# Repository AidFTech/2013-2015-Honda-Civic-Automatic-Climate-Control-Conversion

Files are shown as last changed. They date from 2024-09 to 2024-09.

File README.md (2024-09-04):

# 2013-2015 Honda Civic Automatic Climate Control Conversion

This device allows for a plug-and-play conversion of the manual climate control provided in the 2013-2015 Civic LX, GX, HF, and Si (US) to the automatic climate control provided in the EX and EX-L trims.

All files required to build and program the device are included in this repository.

Refer to [this](https://youtu.be/0c5TGwSvMb4) YouTube video for instructions if you have never built a black box before.

Questions? Comments? Concerns? Email me at [aidancivicminded@gmail.com](aidancivicminded@gmail.com).

## PCB Fabrication

The Gerber files required for PCB fabrication can be downloaded from Hardware/PCB. This folder also contains the EasyEDA PCB and schematic files in JSON form. These can be loaded into the EasyEDA online editor for part number references as shown in the instruction video. The parts lists can be found under ./Bill of Materials. To place an order from DigiKey, use the file "BOM_9th gen Civic Automatic Climate Control Conversion_BulkOrder.csv"

## Enclosure Fabrication

The enclosure model files are included in Hardware/Enclosure.

## Programming

This device uses an AVR Atmega328P microcontroller with Arduino bootloader. The Arduino software is free to download from [this page](https://www.arduino.cc/en/software), and the Arduino Uno can be ordered from the same website. All code for this device can be found under Software/Auto_Climate_CAN_Filter.

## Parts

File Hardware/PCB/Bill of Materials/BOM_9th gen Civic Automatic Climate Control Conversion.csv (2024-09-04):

ID | Name | Designator | Footprint | Quantity | Manufacturer Part | Manufacturer | Supplier | Supplier Part
1 | 100u | C1 | CAP-D8.0-F3.5 | 1 | 50ZLH100MEFC8X11.5 | Rubycon | Digi-Key | 1189-2327-ND
2 | 0.1uF | C2,C4,C7,C9,C10,C13,C16,C20 | C0603 | 8 | 0603B104K101CT | Walsin Technology Corporation | Digi-Key | 1292-1392-1-ND
3 | 470uF | C3 | CAP-D8.0-F3.5 | 1 | 860020474014 | Würth Elektronik | Digi-Key | 732-8831-1-ND
4 | 22pF | C5,C6,C8,C14,C15,C17 | C0603 | 6 | 0603N220F500CT | Walsin Technology Corporation | Digi-Key | 1292-1500-1-ND
5 | 560pF | C11,C12,C18,C19 | C0603 | 4 | 06031C561KAT2A | AVX Corporation | Digi-Key | 478-5002-1-ND
6 | PESD1CAN | D1,D2 | SOT-23_L2.9-W1.3-P1.90-LS2.4-BR | 2 | PESD1CAN-UX | Nexperia USA Inc. | Digi-Key | 1727-1306-1-ND
7 | MX34032UF2 | J1 | MX34032UF2 | 1 | MX34032UF2 | JAE Electronics | Digi-Key | 670-2910-ND
8 | 53254-0270 | J2 | MOLEX_53254-0270 | 1 | 532540270 | Molex | Digi-Key | WM18999-ND
9 | B04B-PASK | J3,J4 | CONN-TH_B04B-PASK-LF-SN | 2 | B04B-PASK(LF)(SN) | JST Sales America Inc. | Digi-Key | 455-1819-ND
10 | 5018763240 | J5 | CONN-TH_32P-P2.00-S2.00_L9.1-W34.0 | 1 | 5018763240 | Molex | Digi-Key | WM12318-ND
11 | S2B-XH-A-BK(LF)(SN) | J6 | CONN-TH_S2B-XH-A-LF-SN | 1 | S2B-XH-A-BK(LF)(SN) | JST | Digi-Key | 455-S2B-XH-A-ND
12 | HDR-M-2.54_1x4 | J7 | HDR-M-2.54_1X4 | 1 | 61300411121 | Würth Elektronik | Digi-Key | 732-5317-ND
13 | SI2347DS-T1-GE3 | Q1 | SOT-23-3_L2.9-W1.3-P1.83-LS2.4-BR-1 | 1 | SI2347DS-T1-GE3 | Vishay Siliconix | Digi-Key | SI2347DS-T1-GE3CT-ND
14 | DMN67D8LW-13 | Q2,Q3 | SOT-323-3_L2.2-W1.3-P1.30-LS2.1-BR | 2 | DMN67D8LW-13 | Diodes Incorporated | Digi-Key | DMN67D8LW-13DICT-ND
15 | 4.7k | R1,R2,R4,R7 | R0603 | 4 | RC0603FR-074K7P | Yageo | Digi-Key | YAG1304CT-ND
16 | 10k | R3 | R0603 | 1 | RNCP0603FTD10K0 | Stackpole Electronics Inc | Digi-Key | RNCP0603FTD10K0CT-ND
17 | 100 | R5,R6,R8,R9,R10 | R0603 | 5 | CRCW0603100RFKEAHP | Vishay Dale | Digi-Key | 541-100SCT-ND
18 | 7805 | U1 | SOT-223-4_L6.5-W3.5-P2.30-LS7.0-BR | 1 | LM7805MP/NOPB | Texas Instruments | Digi-Key | 296-44517-1-ND
19 | ATMEGA328P-PU | U2 | DIP-28_L34.6-W7.3-P2.54-LS10.2-BL | 1 | ATMEGA328P-PU | Microchip Technology | Digi-Key | ATMEGA328P-PU-ND
20 | MCP4921T-E/MS | U3 | 8-SOIC-3.9MM | 1 | MCP4921-E/SN | Microchip Technology | Digi-Key | MCP4921-E/SN-ND
21 | MCP2515T-I/SO | U4,U7 | SOIC-18_L11.6-W7.5-P1.27-LS10.3-BL | 2 | MCP2515T-I/SO | Microchip Technology | Digi-Key | MCP2515T-I/SOCT-ND
22 | MCP2551T-I/SN | U5,U6 | SOIC-8_L4.9-W3.9-P1.27-LS6.0-BL-2 | 2 | MCP2551-I/SN | Microchip Technology | Digi-Key | MCP2551-I/SN-ND
23 | 16MHz | X1,X2,X3 | HC-49US-SMD_L7.0-W4.1 | 3 | ECS-160-20-3X-EN-TR | ECS Inc. | Digi-Key | XC1793CT-ND

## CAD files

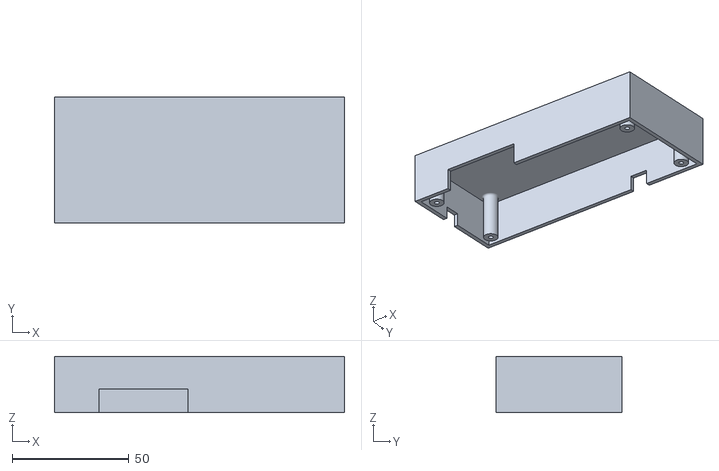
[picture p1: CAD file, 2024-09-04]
Hardware/Enclosure/Enclosure Top.stl
124.0 x 54.0 x 24.0

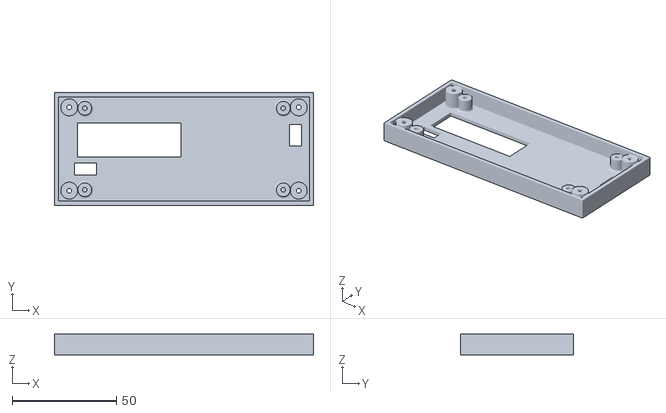
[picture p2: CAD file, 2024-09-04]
Hardware/Enclosure/Enclosure Bottom.stl
124.0 x 54.0 x 10.0

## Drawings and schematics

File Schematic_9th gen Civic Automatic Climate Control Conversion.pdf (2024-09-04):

## JAE MX340032F2

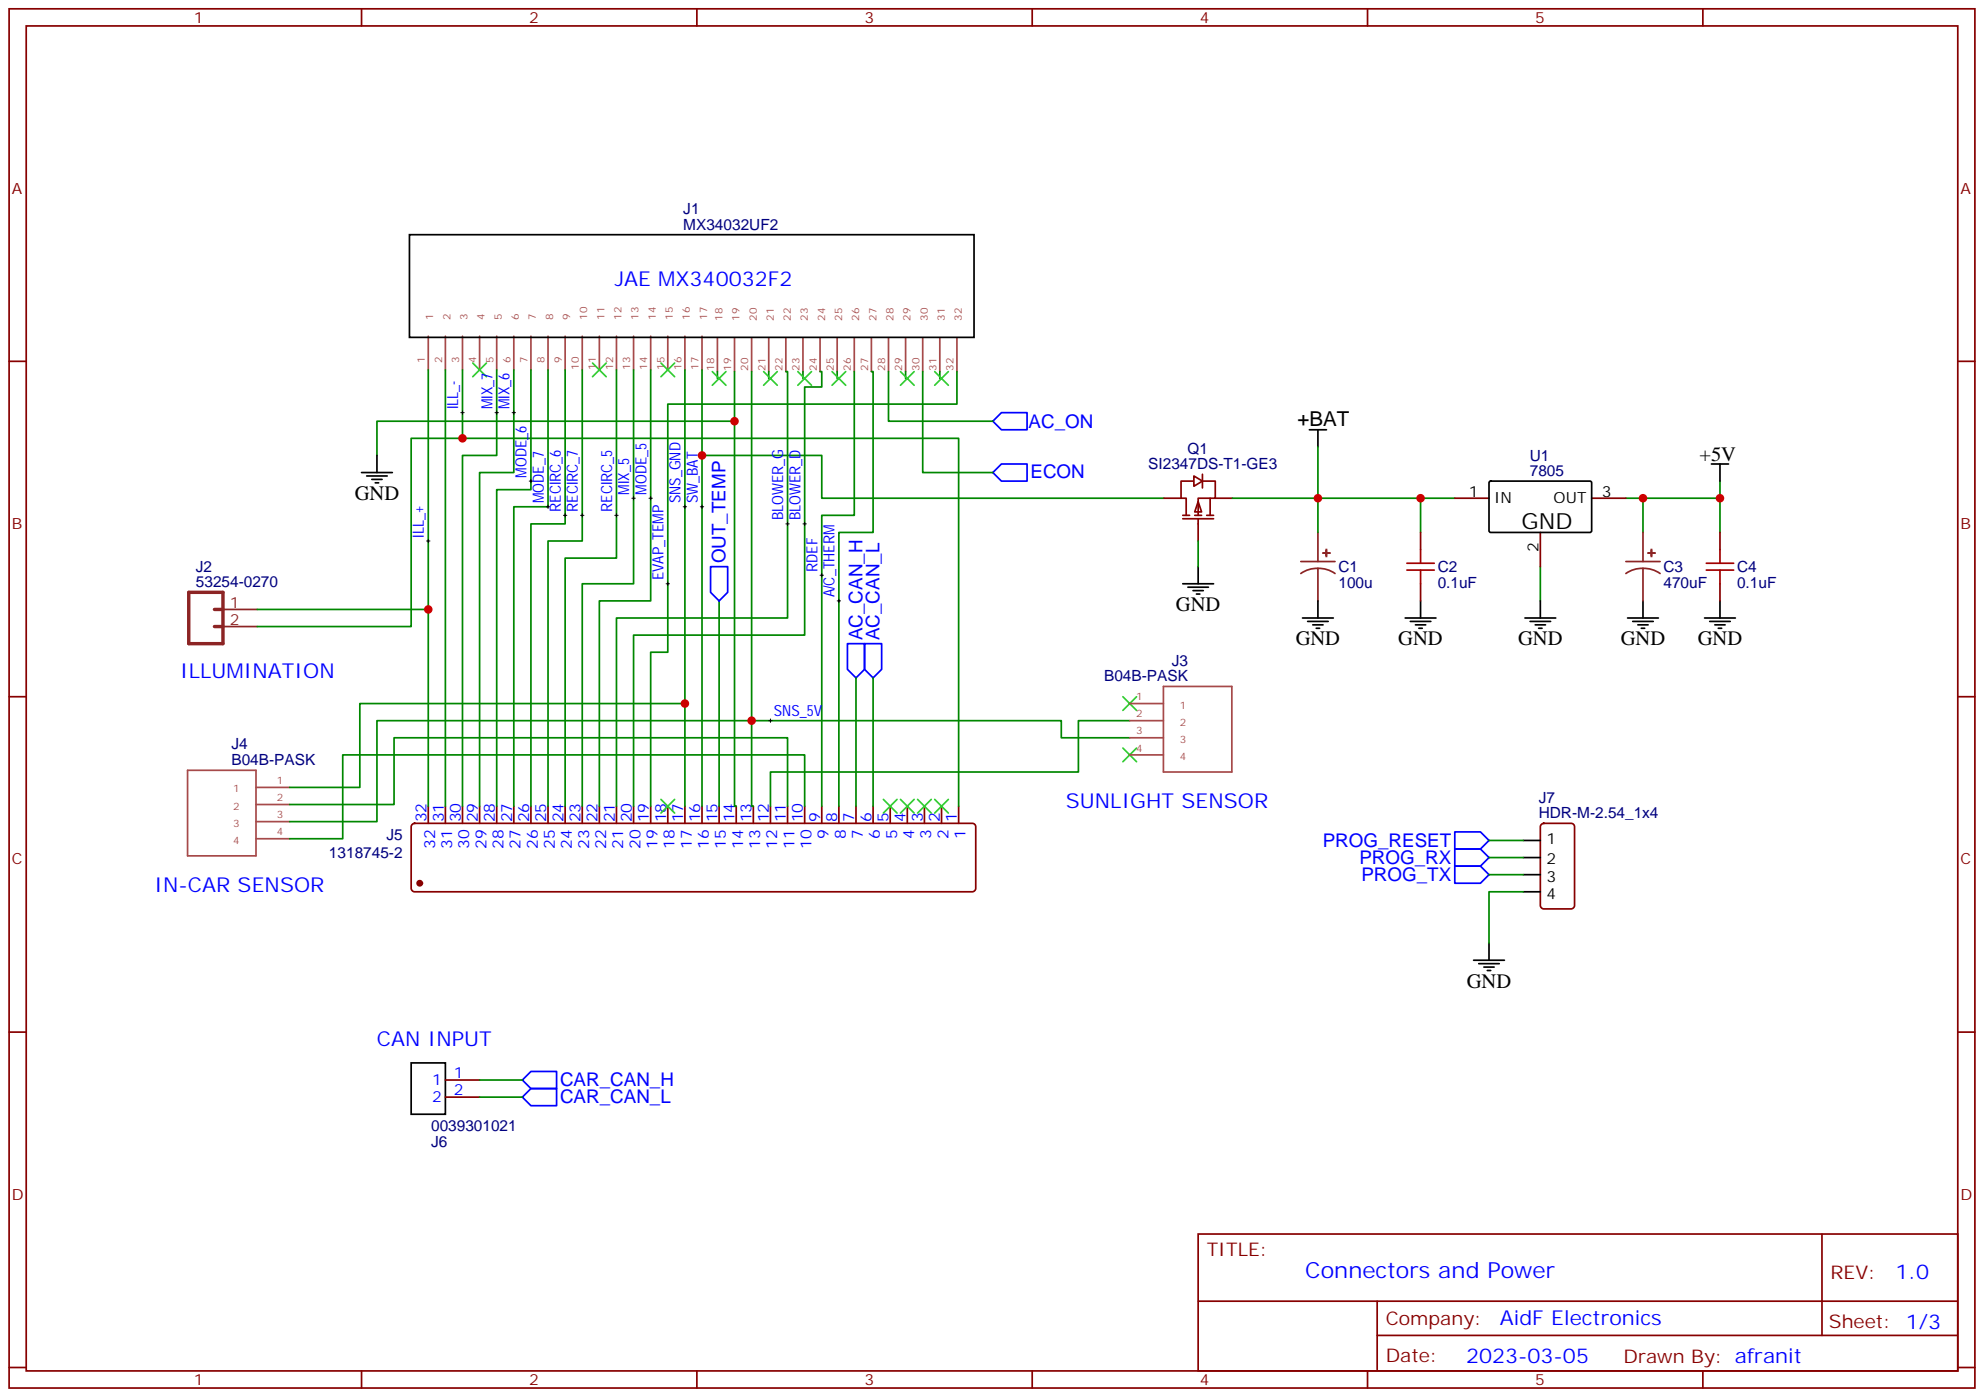
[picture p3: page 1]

# GNDAC_ON

## RESET

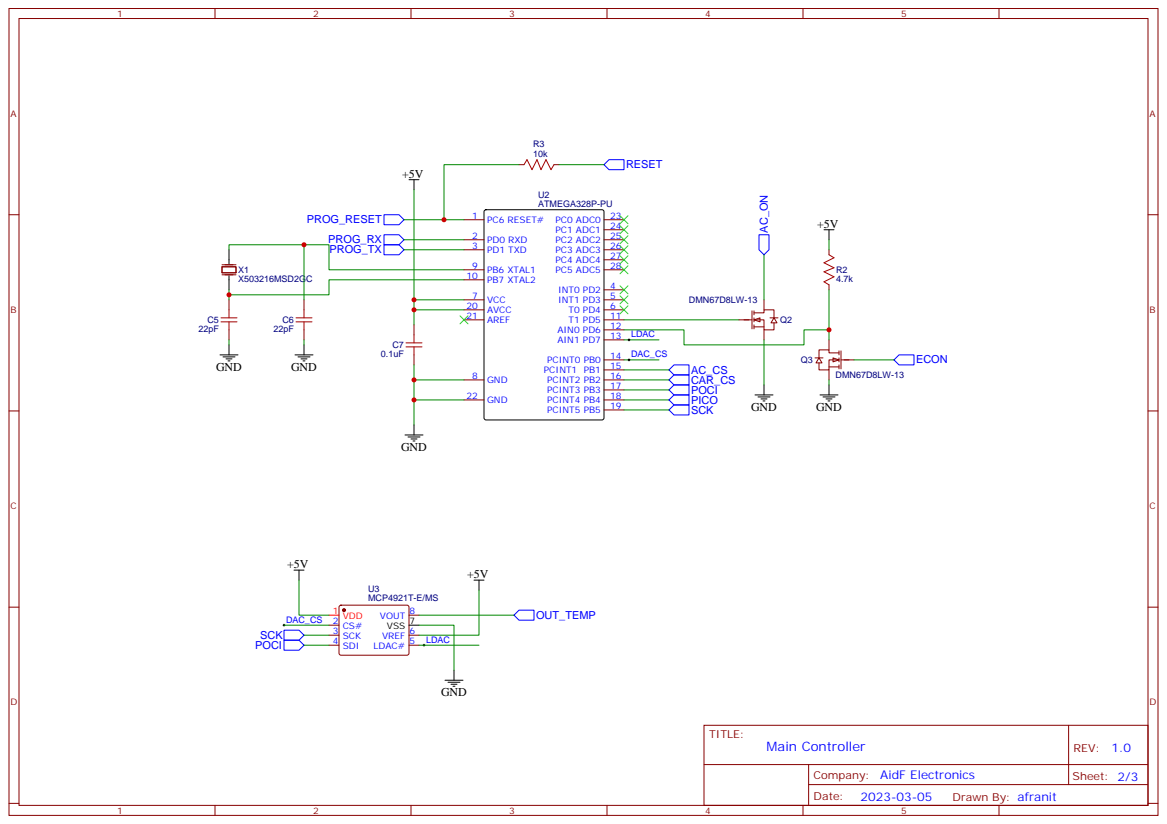
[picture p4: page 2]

## RESET

## POCI

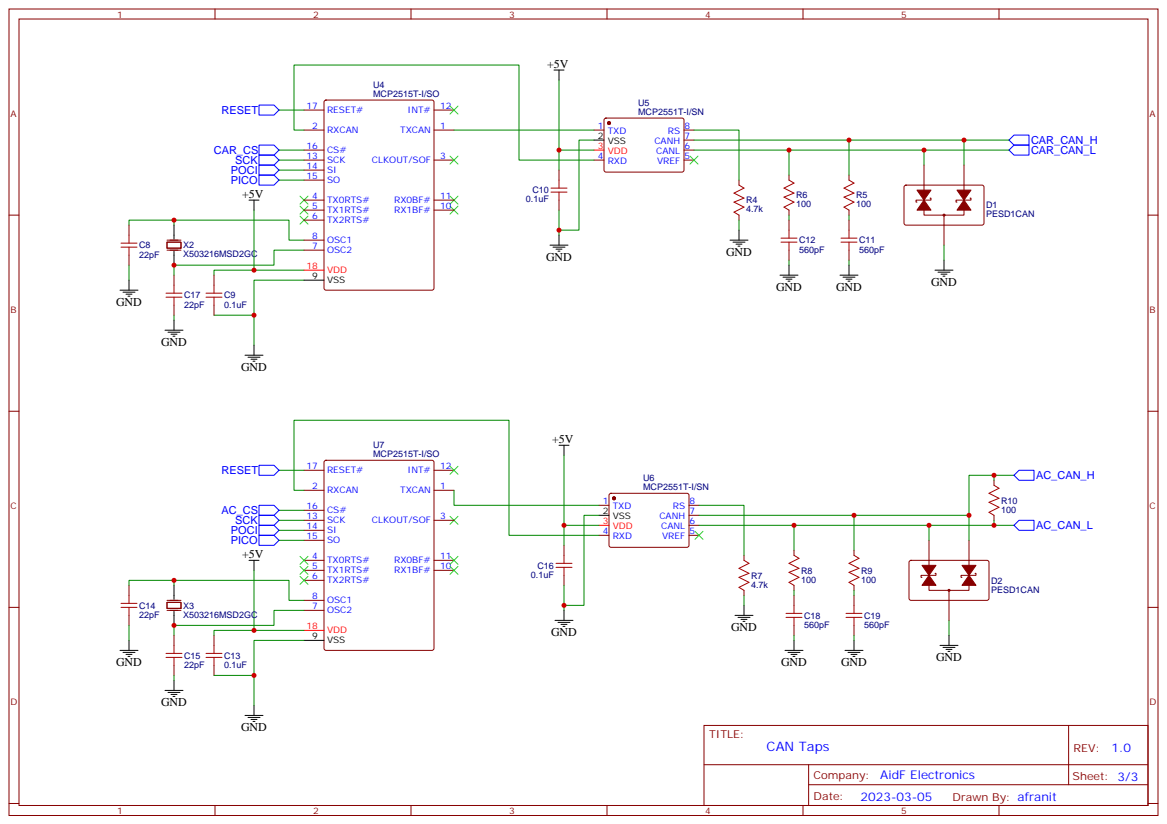
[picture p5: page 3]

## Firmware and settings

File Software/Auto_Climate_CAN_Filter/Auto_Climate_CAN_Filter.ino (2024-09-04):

#include <stdint.h>
#include <mcp2515.h>
#include <SPI.h>

#include "Auto_Climate_Translator.h"

#define AC_PIN 5
#define ECON_PIN 6
#define LDAC 7
#define DAC_CS 8

MCP2515 can_car(10);
MCP2515 can_unit(9);

AutoClimateTranslator auto_translator(&can_car, &can_unit, AC_PIN, ECON_PIN, DAC_CS, LDAC); 

void setup() {
	can_car.reset();
	can_car.setBitrate(CAN_125KBPS);
	can_car.setNormalMode();
	
	can_unit.reset();
	can_unit.setBitrate(CAN_125KBPS);
	can_unit.setNormalMode();
	
	pinMode(LDAC, OUTPUT);
	pinMode(DAC_CS, OUTPUT);
	auto_translator.sendStartDAC();
}

void loop() {
	auto_translator.getCANMessages();
}

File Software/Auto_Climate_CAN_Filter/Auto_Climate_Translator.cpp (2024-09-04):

#include "Auto_Climate_Translator.h"

AutoClimateTranslator::AutoClimateTranslator(MCP2515* car_can, MCP2515* unit_can, uint8_t ac_pin, uint8_t econ_pin, uint8_t dac_cs, uint8_t dac_latch) {
	this->car_can = car_can;
	this->unit_can = unit_can;
	
	this->ac_pin = ac_pin;
	this->econ_pin = econ_pin;
	
	this->dac_cs = dac_cs;
	this->dac_latch = dac_latch;
	
	pinMode(this->ac_pin, OUTPUT);
	digitalWrite(this->ac_pin, LOW);
	
	#ifdef ECONOMY_AVAILABLE
	pinMode(this->econ_pin, INPUT);
	#endif
}

void AutoClimateTranslator::getCANMessages() {
	bool msg_received = false;
	can_frame can_msg;
	
	//Check car messages first.
	if(car_can->readMessage(&can_msg) == MCP2515::ERROR_OK)
		msg_received = true;
	
	if(msg_received) {
		interpretCarMessage(&can_msg);
		unit_can->sendMessage(&can_msg);
	}
	
	//Check unit messages.
	msg_received = false;
	
	if(unit_can->readMessage(&can_msg) == MCP2515::ERROR_OK)
		msg_received = true;
	
	if(msg_received) {
		interpretUnitMessage(&can_msg);
		if(can_msg.can_id != CLIMATE_MSG_1 && can_msg.can_id != CLIMATE_MSG_2 && can_msg.can_id != CLIMATE_MSG_3)
			car_can->sendMessage(&can_msg);
	}
}

void AutoClimateTranslator::sendStartDAC() {
	dac_mcp.begin(this->dac_cs);
	dac_mcp.fastWriteA(1652);
	
	pinMode(this->dac_latch, OUTPUT);
	digitalWrite(this->dac_latch, LOW);
}

void AutoClimateTranslator::interpretCarMessage(can_frame* the_message) {
	if(the_message->can_id == TEMP_DISPLAY_ID) {
		const int16_t temp = the_message->data[2] - 0x28;
		const bool fahrenheit = ((the_message->data[0]&(0b1<<5)) != 0);
		
		uint16_t dac_temp = getTempVoltage(temp, fahrenheit);
		if((dac_temp&0xF000) != 0)
			dac_temp &= 0xFFF;
		
		dac_mcp.fastWriteA(dac_temp);
	} 
	#ifdef ECONOMY_AVAILABLE
	else if(the_message->can_id == ECON_ID) {
		if(digitalRead(this->econ_pin) == HIGH) //Economy mode is on.
			the_message->data[3] = the_message->data[3]|0x20;
	}
	#endif
}

void AutoClimateTranslator::interpretUnitMessage(can_frame* the_message) {
	if(the_message->can_id == CLIMATE_MSG_1) {
		const bool ac_prohibit = ((the_message->data[5]&0x1) != 0);
		
		if(ac_prohibit)
			digitalWrite(ac_pin, LOW);
		else
			digitalWrite(ac_pin, HIGH);
	}
}

uint16_t AutoClimateTranslator::getTempVoltage(int16_t temp, const bool fahrenheit) {
	if(!fahrenheit)
		temp = temp*2;
	else
		temp = (temp - 32) * 10 / 9;
	
	//TODO: Adjust for more extreme temps.
	if(temp > 80) {
		const int32_t m = -21, b = 2752;
		return temp*m+b;
	} else if(temp < 20 && temp >= -20) {
		const int32_t m = -23, b = 2752;
		return temp*m+b;
	} else if(temp < -20) {
		const int32_t m = -24, b = 2752;
		return temp*m+b;
	} else {
		const int32_t m = -22, b = 2752;
		return temp*m+b;
	}
}
